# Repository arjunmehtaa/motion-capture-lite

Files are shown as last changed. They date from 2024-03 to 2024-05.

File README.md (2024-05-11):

# Motion Capture Lite
Project created as part of the FYDP Capstone (ECE 2024).

Created by: Arjun Mehta, Aryaman Singh, Kevin Kalathil, Nicolas Bao

## Project Abstract
The objective of this project is to build a “lite” motion-capture device that can accurately track small objects that are normally too difficult to track using just a camera. The device uses semi-passive imperceptible markers, which refer to projectors that illuminate small LED marker tags placed on objects. The marker tags are equipped with photosensors to detect light from a projector, and a microcontroller. The markers will process and communicate the results back to a computer where a software tool, through signal processing, converts recorded motion data from the device into 3D motion vectors and allows for real-time tracking.

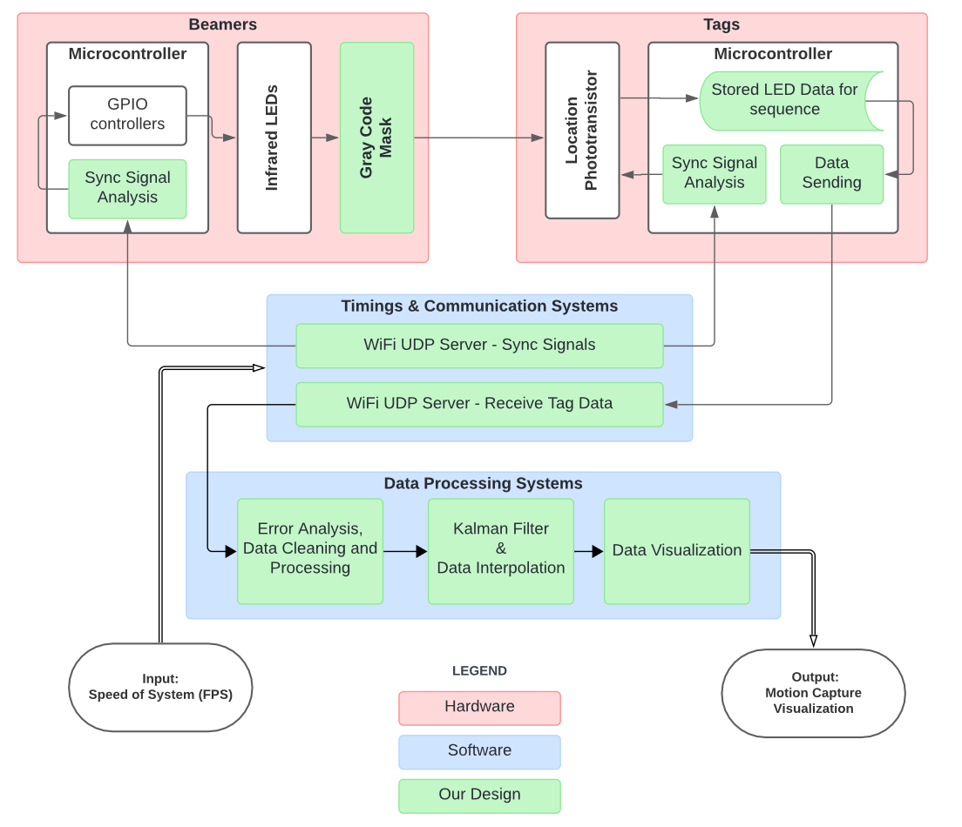
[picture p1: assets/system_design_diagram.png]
System Design


## Files
- `README.md`: This file.
- `report.pdf`: The final report for the project.
- `poster.pdf`: Poster for Capstone Presentation.

- `beamer_wifi.ino`: Arduino code for the beamers
- `tag_wifi.ino`: Arduino code for the tags
  
- `udp_server.py`: Python code for the server (receives data from the tags)
- `udp_server_calibrate.py`: Optional tool to help calibrate the system
- `visualizer.py`: 3D Visualization tool for tag motion (requires `matplotlib`)

- `rust_sender/*`: Rust code for the sender (sends data to the tags)

- `schematics/*`: Schematics for the project (tag and beamer)
- `old/*`: Old code and files - please ignore!

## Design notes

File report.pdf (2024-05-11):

University of Waterloo
Faculty of Engineering
Department of Electrical and Computer Engineering

# Motion Capture Lite

# Final Report

Group Number 14
Prepared by:
Name | Student Number | Email
Aryaman Singh | 20815224 | a55sing@uwaterloo.ca
Arjun Mehta | 20839709 | a47mehta@uwaterloo.ca
Kevin Kalathil | 20846153 | kkalathi@uwaterloo.ca
Nicolas Bao | 20828231 | n3bao@uwaterloo.ca

Consultant Name: Murray Dunne

Date: February 25, 2024

# Abstract

Motion Capture is a common technique used to track the movement of objects digitally. Used extensively by the entertainment, sports, and robotics industries, existing solutions are generally expensive and complex. They typically involve elaborate suits, large camera setups, and human-centered tracking. The objective of this project is to build a “lite” motion-capture device that can accurately track small objects that are normally too difficult to track using just a camera. The device uses semi-passive imperceptible markers, which refer to projectors that illuminate small LED marker tags placed on objects. The marker tags are equipped with photosensors to detect light from a projector, and a microcontroller. The markers will process and communicate the results back to a computer where a software tool, through signal processing, converts recorded motion data from the device into 3D motion vectors and allows for real-time tracking. This method allows the device to capture the motion of objects at high speed, using relatively simple and cheap electronics (photosensors and LEDs).

# Acknowledgments

We want to, first and foremost, express our gratitude to Professor Murray Dunne for his invaluable assistance over the past year. His guidance has played a crucial role in shaping the direction of this project since its inception, and we deeply appreciate his encouraging words and unwavering support throughout the entire process.

We are also extremely thankful to the original authors of Prakash: Lighting Aware Motion Capture using Photosensing Markers and Multiplexed Illuminators [1], which was published by the Mitsubishi Electric Research Laboratories (MERL) in Cambridge, MA - this paper was the original inspiration for our work, and though our project differs in implementation, it has been essential in our work.

Finally, we are thankful to the entire ECE department, professors, and TAs for their continued support through the FYDP process.

### University of Waterloo Territorial Acknowledgment

The University of Waterloo acknowledges that much of our work takes place on the traditional territory of the Neutral, Anishinaabeg, and Haudenosaunee peoples. Our main campus is situated on the Haldimand Tract, the land granted to the Six Nations that includes six miles on each side of the Grand River. Our active work toward reconciliation takes place across our campuses through research, learning, teaching, and community building, and is co-ordinated within the Office of Indigenous Relations.

# Table of Contents

Abstract | 1
Acknowledgments | 3
University of Waterloo Territorial Acknowledgment | 3
Table of Contents | 4
List of Figures | 5
List of Tables | 6
1. High-Level Description of Project | 7
1.1 Motivation | 7
1.2 Project Objective | 7
1.3 Block Diagram | 8
2. Project Specifications | 10
2.1 Functional Specifications | 10
2.2. Non-functional Specifications | 11
Table 2. Non-functional specifications | 11
3. Detailed Design | 12
3.1 Tags | 12
3.1.1. Physical Design | 12
3.1.2 Software Design | 14
3.2 Beamers | 16
3.2.1 Physical Design | 16
3.2.2 Software Design | 18
3.3. Timings and Communication | 20
3.3.1 Time Modulation Decision | 20
3.3.2 Beamer Timing Design | 20
3.3.3 Communication Protocol - WiFi | 21
3.4 Data Processing Software | 24
3.4.1 Software Architecture | 24
3.4.2 Data Visualization | 25
5. Discussion & Conclusions | 28
5.1 Evaluation of Final Design | 28
5.2 Use of Advanced Knowledge | 28
5.3 Creativity, Novelty, Elegance | 29
5.4 Quality of Risk Assessment | 30
5.5 Student Workload | 31
References | 32

# List of Figures

Figure Name | Page
Figure 1. Block Diagram of Motion Capture Lite | 8
Figure 2. Diagrams showing connections on the tag microcontroller | 13
Figure 3. Diagrams showing connections on the phototransistor circuit | 13
Figure 4. Image displaying PCB for tag and microcontroller | 14

Figure 5. Arduino (.ino) code snippet for tag microcontroller, showing the four steps

for reading, storing, and sending the values. | 15
Figure 6. Circuit diagram for the buck converter on the beamer PCB | 16
Figure 7. LED and Mosfet diagrams for beamer PCB | 17
Figure 8. Circuity diagram showing MC terminal connections and GPIO connections | 17
Figure 9. 3D models of the beamer casing | 18

Figure 10. Sample 3D-printed casing with microcontroller and PCB - important

components are labeled in the diagram for convenience. | 18
Figure 11. Timing diagram for beamer | 20
Figure 12. Block diagram of a 6 LED beamer | 21

Figure 13: Block diagram depicting wireless communication between server-beamer

and server-tag | 22
Figure 14. Flow Architecture of the Location Processing Algorithm. | 24
Figure 15. Demo of Data Visualization using Python’s Matplotlib. | 26
Figure 16. Showing how the trail animations were created in Python Matplotlib | 27

# List of Tables

Table Name | Page
Table 1. Functional Specifications | 10
Table 2. Non-functional specifications | 11
Table 3. Requirements for phototransistor on tag | 12

Table 4. Variation of ADC Values from the microcontroller depending on the distance

between the tag and beamer | 13
Table 5. Requirements of Location LED on Beamer | 16
Table 6. Performance of LED detection depending on reading window | 19

Table 7. Variation of dropped packets with respect to the interval between sync

signals | 23
Table 8. Decision Matrix for visualization tool | 25
Table 9. Evaluation of functional requirement analysis | 28
Table 10. Quality of Risk Assessment table | 30
Table 11. Student Workload Table | 31

# 1. High-Level Description of Project

## 1.1 Motivation

Motion Capture is a common technique used to track the movement of objects digitally. The global market for motion capture is valued at around US$180M as of 2022 and is expected to reach US$600M by 2030. [2] Used extensively by the entertainment, sports, and robotics industries, existing solutions are generally expensive and complex, with most options costing thousands of dollars. [3] They typically involve elaborate suits, large camera setups, and human-centered tracking. The objective of this project is to build a “lite” motion-capture device that can accurately track small objects such as in-game props that are normally too difficult and too costly to track using a camera.

The device uses semi-passive imperceptible markers [1], which refer to projectors that illuminate small LED marker tags placed on objects. The marker tags are equipped with photosensors to detect light from a projector, and a microcontroller. The markers process and communicate the results back to a computer where a software tool, through signal processing, converts recorded motion data from the device into 3D motion vectors and allows for real-time tracking. This method allows the device to capture the motion of objects at high speed, using relatively simple and cheap electronics (photosensors and LEDs).

## 1.2 Project Objective

The objective of this project is to design a relatively low-cost motion capture system to track objects and props using semi-passive imperceptible markers and photosensors. The sensors process and send results to a computer, where the captured data can be used to visualize objects in motion.

## 1.3 Block Diagram

The block diagram for our project is as follows:

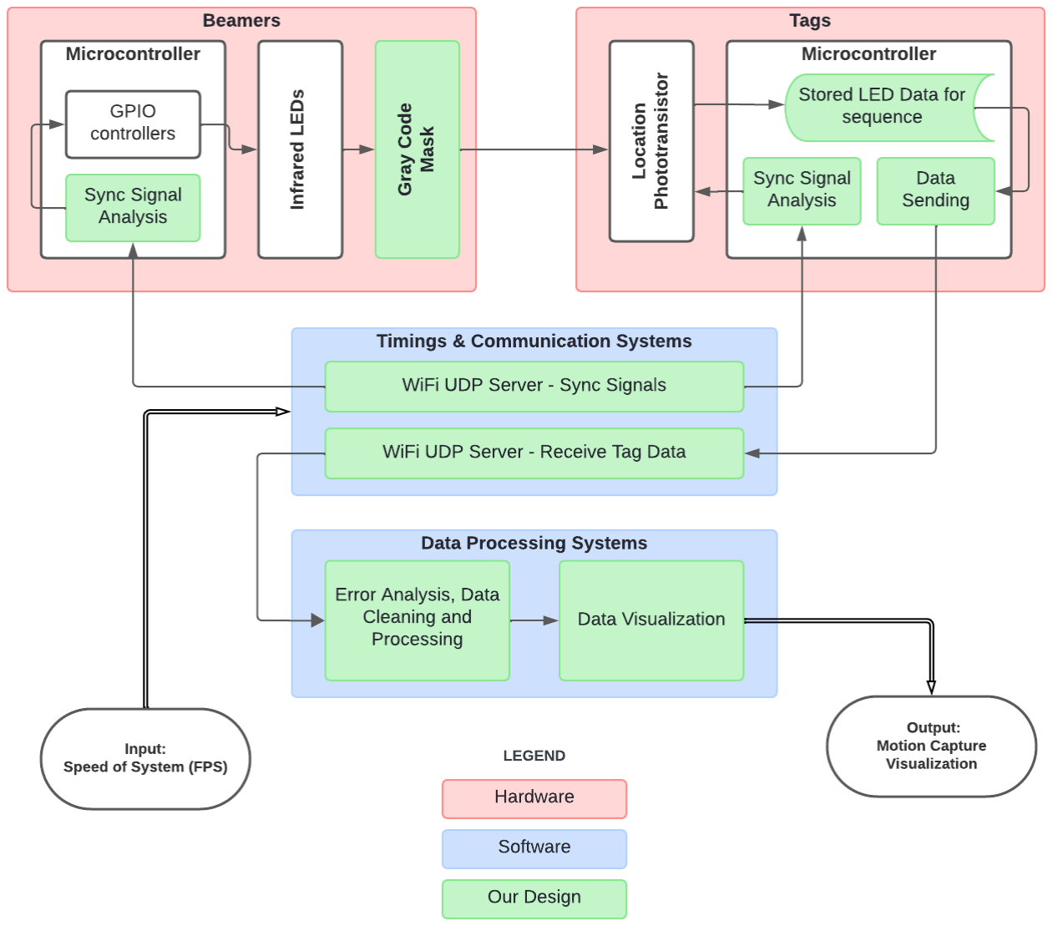
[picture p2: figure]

Figure 1. Block Diagram of Motion Capture Lite

We have 4 subsystems as part of our project:

### 1. Beamers (Transmitters): The beamer components consist of a microcontroller, which

receives a SYNC signal to begin transmitting. The transmission happens using the GPIO pins of the microcontroller, which turn on each of the 6 LEDs sequentially, at speeds up to 10ms per LED. A gray code mask is placed in front of the LEDs to uniquely identify each beamer. A single beamer is used to identify a tag’s location within a specific axis.

2. Tags (Receiver): The tags are to be attached to the object of interest and each tag will be used as a reference to describe the object’s movement. The tag begins observing the LEDs using its phototransistor when it receives a SYNC signal, stores the sequential data for all 6 LEDs, and sends the data to the server when it has received all the required data.

### 3. Timings & Communication Systems: This subsystem consists of a server that sends a

SYNC signal to all the beamers and tags at the same time, ensuring that the beamers and tags are coordinated correctly. This subsystem also receives the data from the tag microcontroller and sends it to the data processing systems.

### 4. Data Processing System: This subsystem takes in the voltage values communicated by

the tag to the server, performs error correction and data analysis on it, and then parses the data to determine the position of the tag in 2D/3D space. Data visualization software is used to display the position.

# 2. Project Specifications

## 2.1 Functional Specifications

Specification | Subsystem | Description | Necessity
Sensor integration | Tags (Receiver) | Each tag contains a phototransistor which is used for location tracking. | Essential
Data Processing | Data Processing Software, Tags/Receiver | Take a bitstream from each tag and use Location Vector algorithms such as triangulation to convert raw data from the photosensors into 3D motion data | Essential
Communication | Beamer (Transmitter), Tags (Receiver)

A tag’s microcontroller communicates results from phototransistors to the server. The computer sends a sync signal to all tags and beamers.

Essential

Data Storage | Tags (Receiver) | Tags should maintain a bit stream that will be used to resolve its position. This data is to be stored on the microcontroller’s on-device Flash memory.

Essential

Real-time
streaming

Data Processing
Software, Tags
(Receiver)

The data recorded by the microcontroller should be relayed to software that converts and processes the raw data stream. Real-time streaming enables a better user experience and decreased memory usage on the device.

Non-Essential

Table 1. Functional Specifications

## 2.2. Non-functional Specifications

Specification | Subsystem | Description | Necessity
Lightweight | Tags | As these tags are going to be placed on moving objects, they need to be light. | Essential
Cheap | Tags | Since we may need numerous tags on a single object or we want to track multiple objects simultaneously. We would like the tags to be cheap to produce. | Non-Essential
Portable | Tags | One of the main benefits of this type of motion capture is the simplicity of the system components. This simplicity can also allow for more portable devices

Non-Essential

Scalable | Software, Tags | The system should scale with any number of sensors that are added to the system.

Non-Essential

Table 2. Non-functional specifications

# 3. Detailed Design

## 3.1 Tags

### 3.1.1. Physical Design

The design of the tag is relatively simple - it consists of a phototransistor that is designed to be able to detect when the infrared LED is turned on. The requirements of the phototransistor are as follows:

Angle of Detection | Intensity falloff vs distance | Intensity falloff vs angle | Light spectrum
Narrow | Minimum | Sharp | Infrared
Table 3. Requirements for phototransistor on tag

The phototransistor that we selected is the Würth Elecktronik 1541201NEA400 [4], which fulfills all of these requirements. It is important to note that in the context of our circuit, the phototransistor acts as a current source, and the ADC of the microcontroller reads the voltage across the resistor. This can be seen in the figure below:

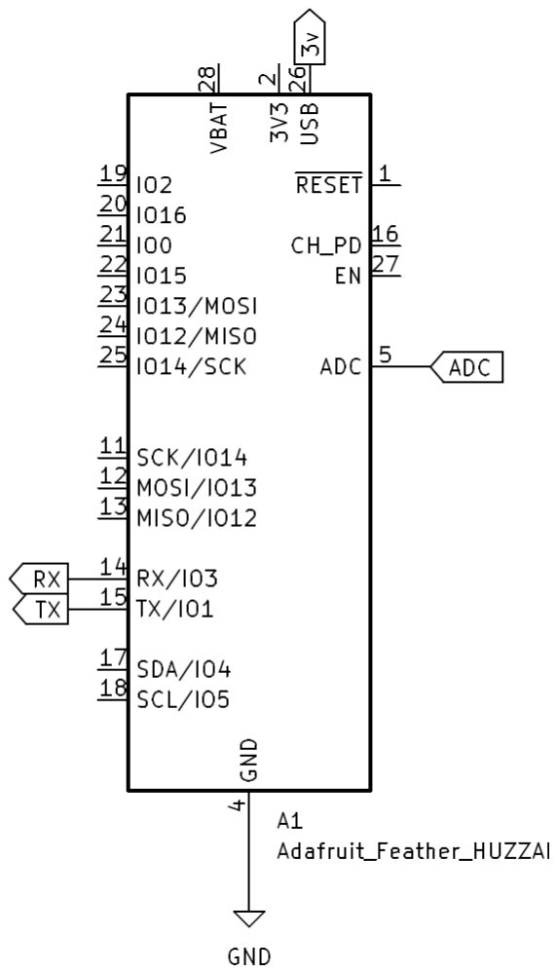
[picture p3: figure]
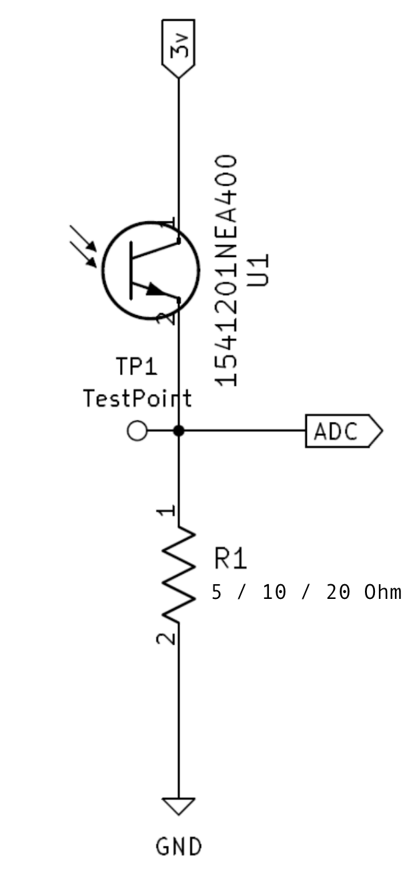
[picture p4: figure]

Figure 2/3. Diagrams showing connections on the tag microcontroller (left) and the phototransistor circuit (right). Note the R1 resistance on the phototransistor circuit.

Thus, our phototransistor can have different sensitivities depending on the value of the resistance. Different sensitivities have different relationships with the voltage values being read by the ADC (Analog to Digital Converter) in the tag. To quantify this relationship, we placed an infrared LED a certain distance away from the phototransistor and observed how the ADC values changed depending on the sensitivity of the photosensor:

Sensitivity of Photosensor Resistor (R1) | Distance between phototransistor (tag) and LED (beamer)
1- 2 inches 1 (High Value) | 2 feet | 4 feet | LED Off (Base Value)
Low - 5 Ohm | 27 | 14 | 7 | 4
Medium - 10 Ohm | 120 | 64 | 12 | 7
High - 20 Ohm | 673 | 104 | 31 | 8
Table 4. Variation of ADC Values from the microcontroller depending on the distance between the tag and beamer (i.e. phototransistor and IR LED)

1 This distance is impractical for the final product due to the 3D printed casing around the tags/beamers, but gives us an idea of the highest possible value the phototransistor can output.

As anticipated, the highest sensitivity resistor yielded the widest range of ADC values. Despite being conducted in ideal conditions, this extended range suggests reliable LED differentiation even in unfavorable lighting. While a higher sensitivity may result in a slightly elevated base value (only 1-4 units more than lower/medium sensitivity resistors in our tests), the benefits outweigh this minor drawback.

Below, we can see our final tag PCB along with the microcontroller:

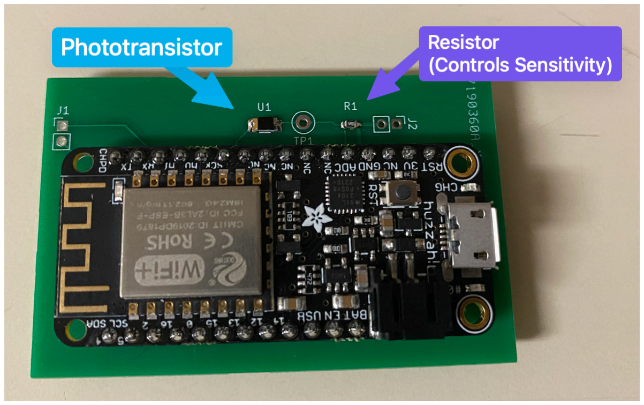
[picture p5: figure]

Figure 4. Image displaying PCB for tag and microcontroller

### 3.1.2 Software Design

The tags are required to meet certain timing deadlines which makes them real-time systems. The software for the tag is responsible for detecting the gray-coded LED signals from the beamers that are being polled by a controller. The tag begins detecting light from the LEDs when the synchronization signal is received from the WiFi server. It periodically checks if it detects an LED, and each time period corresponds to a different LED. At any given point, only one LED would be on. Originally, we had designed our tags to decode the gray-coded signals themselves, by setting a minimum and maximum voltage reading which would count as an LED being on. However, we now send the raw ADC values for each sequence directly to the WiFi server, thus reducing the processing on the tag end.

The overall algorithm can be simplified to these 4 steps:

### 1. Receive a SYNC signal from the server: Note that since reading the contents of a UDP

packet takes time, we simply use the presence of a UDP packet to indicate synchronization.
2. Set inputVoltage for LED: During the reading window for any given LED, set inputVoltage to be the maximum voltage read in that window
- Note that voltage here does not refer to V, but rather the unitless value generated by the ADC.
3. Add current value to packet: When the reading window for any given LED is over, add the inputVoltage to the packet.
4. Send packet to server: When all 6 LEDs have been read, send the packet to the server.

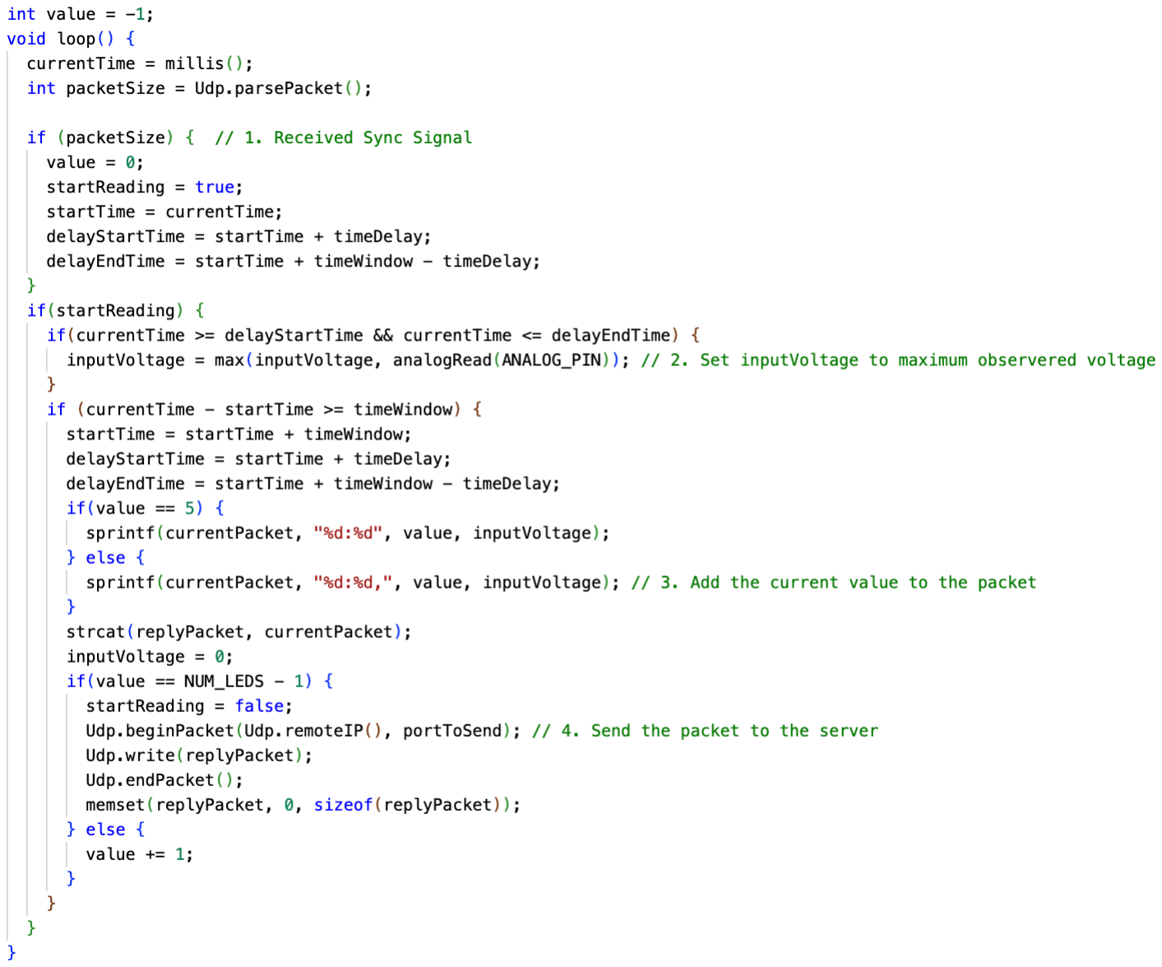
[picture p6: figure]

Figure 5. Arduino (.ino) code snippet for tag microcontroller, showing the four steps for reading, storing, and sending the values.

## 3.2 Beamers

### 3.2.1 Physical Design

The beamer's core function is to control the on/off states of 6 location LEDs. These LEDs, along with the gray code mask, enable the tag's positional detection of the beamers. The pivotal element in the beamer design is the LED, which must meet the following requirements:

Brightness | Cost | Angle | Wavelength
High | Low | Narrow (can be done with physical design) | Infrared
Table 5. Requirements of Location LED on Beamer

The LED we chose is the VSMA 1094250 [5], which fulfilled all of these requirements. Only 1 LED would be turned on at a time, which meant that we did not have to account for the power requirements of all LEDs being on at the same time.

However, since these LEDs require 3V at 1A (which is more than the board power supply of 3.3V at 250 mA), an external power source is needed. A 9V battery is chosen as our power source due to its simplicity and high availability, and a fuse is attached to the battery for safety. A buck converter is added to step down the voltage to 3.3V, which can be seen in the diagram below:

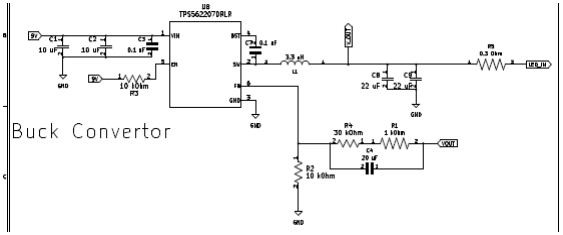
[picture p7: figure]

Figure 6. Circuit diagram for the buck converter on the beamer PCB

Mosfets in series with the LEDs allow us to control which LEDs are on via the GPIO pins of the microcontroller. Figures showing the configuration of the LEDs and Mosfets, as well as how the

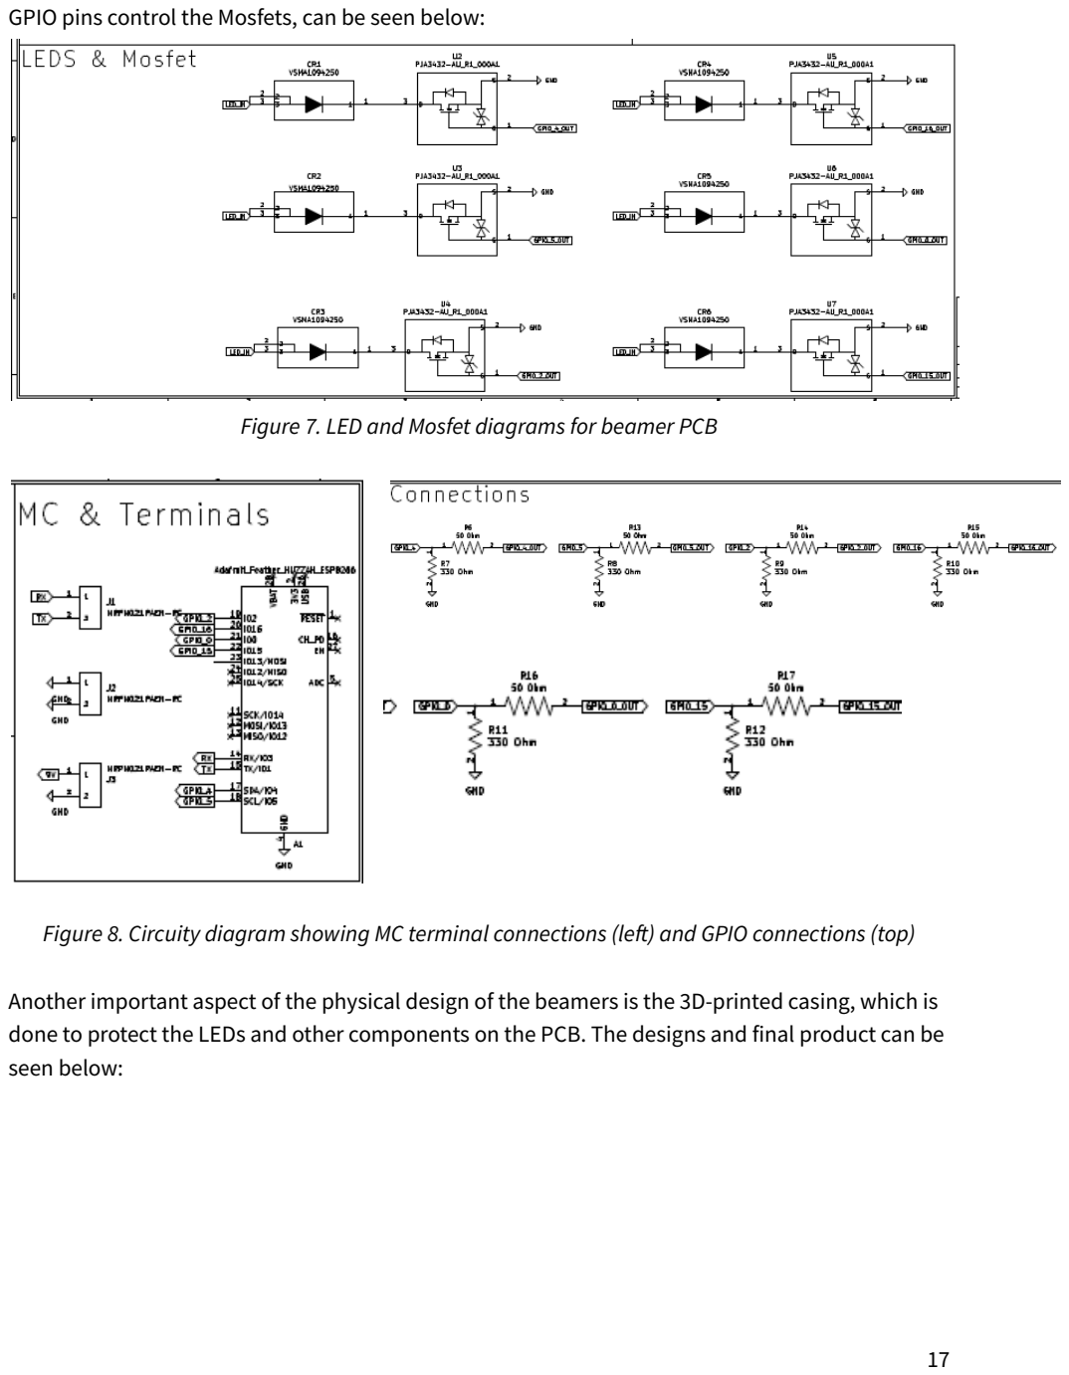
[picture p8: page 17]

GPIO pins control the Mosfets, can be seen below:

Figure 7. LED and Mosfet diagrams for beamer PCB

Figure 8. Circuity diagram showing MC terminal connections (left) and GPIO connections (top)

Another important aspect of the physical design of the beamers is the 3D-printed casing, which is done to protect the LEDs and other components on the PCB. The designs and final product can be seen below:

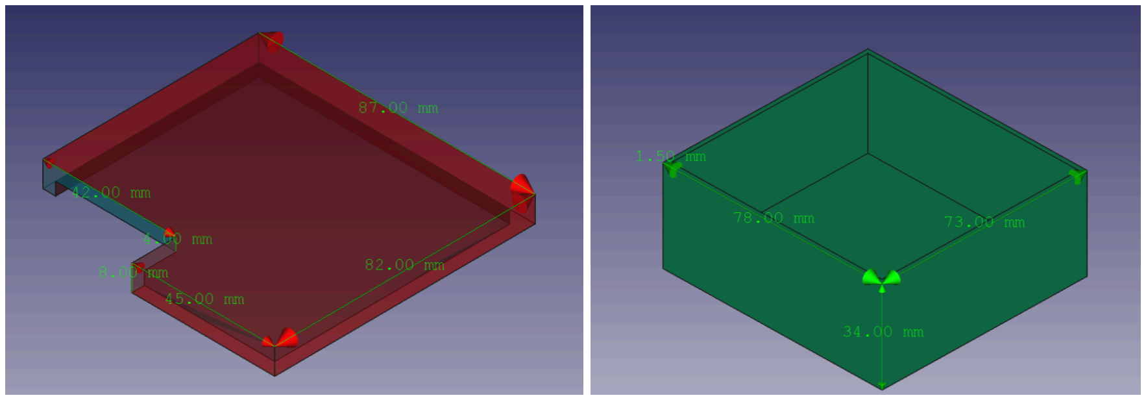
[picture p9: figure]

Figure 9. 3D models of the beamer casing

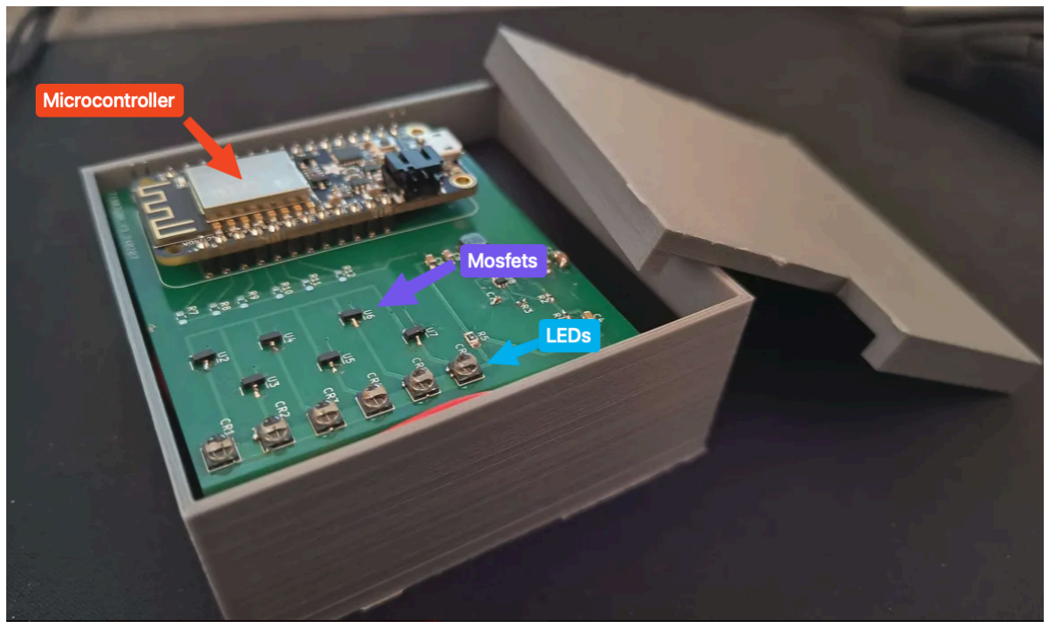
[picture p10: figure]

Figure 10. Sample 3D-printed casing with microcontroller and PCB - important components are labeled in the diagram for convenience.

### 3.2.2 Software Design

The beamers play a crucial role in the timing and speed of our entire system. The rate at which we can cycle between LEDs directly affects the overall speed (i.e. frames per second) we can get in our motion capture system. This requires us to determine the fastest rate at which the LEDs can be cycled through

2 while ensuring that the phototransistor accurately captures each LED without any miscount or mapping errors.

2 For more information about the timing system, see Section 3.3 below.

To test this, we turn on only one LED out of the 6 (LED #3 in this case), and observe how fast we can go without the phototransistor missing the LED or thinking it came from another LED. In other words, the 6 LEDs output 0 0 1 0 0 0, and we expect the phototransistor to return this value. For each time window, we ran this experiment for 100 cycles.

Time Window LED stays on | Number of cycles with missed LEDs | Number of cycles with leaks into previous/next LED reading (i.e LED 2 or LED 4 ) | Comments
100ms | 0 | 1 | The phototransistor can sense the LEDs correctly most of the time for the given time window
50ms | 0 | 2 | The phototransistor can sense the LEDs correctly most of the time for the given time window
10ms | 5 | 8 | The phototransistor can sense the LEDs correctly with a few misses.
6ms | 30 | 50 | The tag is unable to sense the LED within the given time window for a large number of cycles

Table 6. Performance of LED detection depending on reading window

For the 6ms time window, we observe a large number of leaks where the tag believes the phototransistor reading corresponds to the previous/next LED, which could be a result of a slight delay between the tag and beamer receiving the SYNC signal. This indicates that this time window is too small for the phototransistor to sense the LED reliably.

Thus, we concluded that we could go as fast as 10ms per LED without compromising the accuracy of the phototransistor readings (and hence the location calculation) for the tag. A smoothing algorithm and results from previous cycles can be used to make up for any missed readings.

## 3.3. Timings and Communication

### 3.3.1 Time Modulation Decision

One of the downsides of using a phototransistor is its limited resolution as they can not differentiate between light sources. The big question, then, is - how do we avoid detecting light from the wrong LED?

One solution would be to use LEDs that emit light at a specific wavelength and have only one type of phototransistor that can detect that wavelength. There are many issues with this approach, mainly that getting LEDS and phototransistors that can emit and detect in a narrow band of the spectrum is expensive and not aligned with our goal of making the final model product affordable.

We are limited by the cost of LEDs and transistors, so our other option is time modulation. By only reading the values from our sensors during specific time intervals we can “allocate” a time for our beamers to communicate with our sensors.

### 3.3.2 Beamer Timing Design

The beamer’s sole function is to display a gray code light pattern for tags to observe.

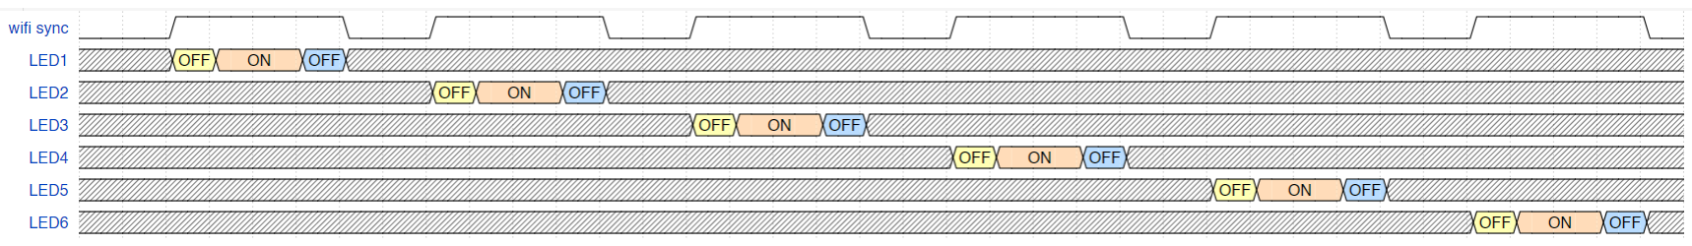
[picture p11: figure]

Figure 11: Timing diagram for one cycle of the beamer’s six LEDs

To further elaborate on how the gray code is sent, the LEDs are lined up and turned on and off in a sequence. Each LED is covered by a 3D-printed gray code mask which blocks light within certain regions only allowing tags within certain regions along the beamer’s plane to observe the emitted light. Since they are enabled sequentially, with each result (observed or not observed), we can halve the possible region where the tag may be located. Refer to Figure 4 for the general layout and timing of a 6 LED tag and gray coding.

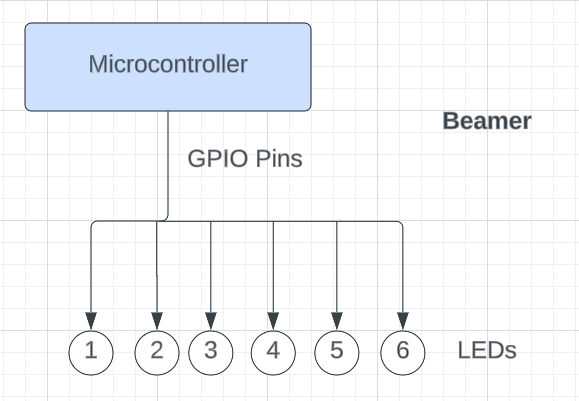
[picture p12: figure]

Figure 12: Block diagram of a 6 LED beamer

### 3.3.3 Communication Protocol - WiFi

Since the system requires high-speed transmission and low-latency data streaming, communication between server-tag and server-beamer is done wirelessly using the UDP protocol, and we use our own router to establish a stable wireless connection between the devices. The UDP socket is set to non-blocking mode, allowing continuity in the case of lost packets. We can handle the lost data by using data from the previous cycle and integrating smoothing algorithms.

The server sends a SYNC signal to a single beamer as well as all the tags at the same time, each listening on their own IP address respectively. Upon receiving the SYNC signal, the beamer turns on its LEDs one-by-one in sequence. The tags return a sequence containing the maximum photo sensor reading they observed for each LED to the server (which is always listening on its IP address on a separate thread). The server then repeats the cycle for the next beamer.

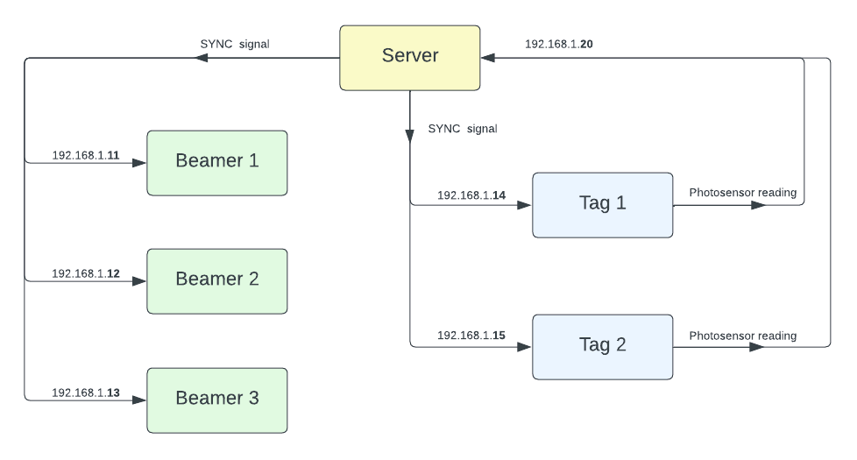
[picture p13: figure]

Figure 13: Block diagram depicting wireless communication between server-beamer and server-tag

Note that the IP addresses used in Figure 6 are placeholders, and they can be configured as required.

So far we have looked at timings for one tag and one beamer, but for our motion capture system to work in 3 dimensions, we need at least three beamers. If the beamers are independent of each other and fire off their LEDs at random, we encounter the same issue of not being able to identify the origins of the LEDs. To resolve this problem, we have decided to synchronize the beamers and have them fire in sequence after one another. To do this, we have to establish a way to coordinate communication across separate beamers.

To manage this task of coordinating separate beamers and tags, we synchronize the entire system using a centralized server stub that handles wireless data transmission, receiving, and processing.

The server, which is a program running on a separate computer, sends out periodic sync signals to all devices (beamers and tags) such that they all know when to emit or observe light, depending on whether the device is a tag or beamer. With the target of 5 frames per second (FPS), we would need to hit an effective clock speed of approximately 11ms per beamer.

We originally intended to send a separate sync signal for each packet but quickly realized that the low latency and high number of packets being transmitted was not feasible.

The following are the results of a test we performed to determine how quickly we could transmit data from the server to a single microcontroller. On the server code, we transmitted a counter value and on the receiver end, we logged the received counter value. If a counter value is missed, that is considered a drop. We tested by sending counter values from 1-200 and analyzing the output on the microcontroller logs.

Time Interval between
synchronization signals

Number of
dropped packets

Comments

50ms | 0 | The target device receives each packet in order and on time
10ms | <=2 | Based on our trials, we never drop more than 5 packets at 10 ms which is recoverable with smoothing, but still not ideal
5ms | <=20 | 20 missed packets in 200 transmissions is not ideal/recoverable.

Table 7. Variation of dropped packets with respect to interval between sync signals

Based on these test results, we then opted for a batching/sequencing approach where the sync signal received represents six cycles. In the case of the beamer, it executes its complete six LED sequence after receiving a sync signal, and the timing delays are handled within the microcontroller code that is flashed on the board. This increases the time between sync signals and decreases the number of packets transmitted by a factor of six. Hence, to achieve an effective clock cycle of 10ms for each LED being toggled, we only need to send packets every 60 ms which is achievable given the current system and its limits (as discussed in Section 3.2.2).

## 3.4 Data Processing Software

### 3.4.1 Software Architecture

Before beginning programming the data processing software, we first conceived what the design architecture should look like. As per our ECE 452 knowledge, we decided that a Pipe & Filter architecture would fit our project the best. Pipe & Filter architecture specializes in software that is heavy in processing, and where the flow of data is fairly linear. See Figure 7 to see an example of Pipe & Filter architecture used to determine the location of the tags using sensor data:

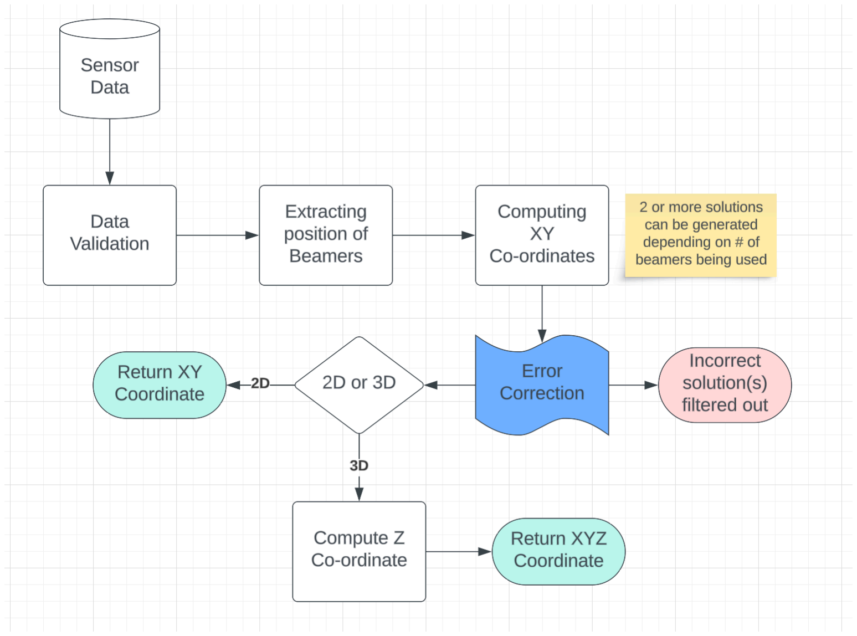
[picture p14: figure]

Figure 14. Flow Architecture of the Location Processing Algorithm. Pipe & Filter architecture can be clearly seen by the each architectural component is a process, and the flow of the data is linear. Error Connection symbolizes one of the filter components.

Data validation is done by simply ensuring that the values received from the tag match the range of the ADC values of the phototransistor, which is determined during our testing of the tag (as explained in Section 3.1.1).

### 3.4.2 Data Visualization

Once we have the coordinates of the tags, our next goal is to visualize the data. Our primary emphasis in developing the motion data visualization is to ensure that we design a system that is fast, easy to run on low-scale hardware, and easy to implement. Given the importance placed on our hardware within our project scope, our objective is to design a system that seamlessly integrates with our hardware, minimizing potential complications.

During the consideration of data visualization software, we explored various options, such as Python's Matplotlib, and Rust's egui, among others. We decided to use a decision matrix to come to the final conclusion on which visualization software to use, with a scoring range from 1 (Low) to 3 (High):

Criteria | Matplotlib (Python) | EGUI (Rust) | Qt (C++) | Tkinter (Python) | Electron (JS/TS)
Ease of Integration 3 | High (3) | High (3) | Low (1) | High (3) | Low (1)
Performance (higher FPS, animation smoothing) | Moderate (2) | High (3) | High (3) | Low (1) | Low (1)
Cross-Platform Support | High (3) | Moderate (2) | Moderate (2) | Medium (3) | High (3)
Flexibility (ability to create custom GUI components) | Moderate (2) | Low (1) | Moderate (2) | Moderate (2) | High (3)
Prior Team Experience | High (3) | Moderate (2) | Low (1) | Medium (2) | High (3)
Visual Appeal | Moderate (2) | Low (1) | Low (1) | Moderate (2) | High (3)
Total | 15 | 12 | 10 | 13 | 14

Table 8. Decision Matrix for visualization tool

3 During the discussion on which visualization software to use, we were already using Rust and Python for parts of our server and networking code, which is why tools that used these languages were given a High rating.

In the end, we ended up using Python’s Matplotlib, primarily due to its ease of use and easy integration with our existing codebase. Another advantage of Matplotlib is its easy implementation of 3D visualization [6], which some other visualization tools did not support.

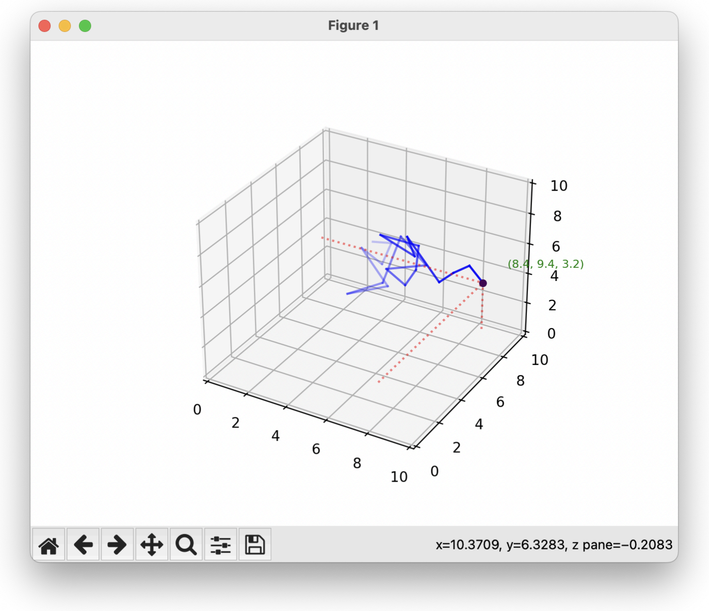
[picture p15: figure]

Figure 15. Demo of Data Visualization using Python’s Matplotlib. The point is labeled and has red lines indicating shadow on the axes.

A very simple animation algorithm is applied to ensure a “smooth” path of the motion capture data can be shown. The previous 20 (or so) points were stored and graphed, and lines connecting these points with decreasing transparency were added to visualize a “trail” behind the point:

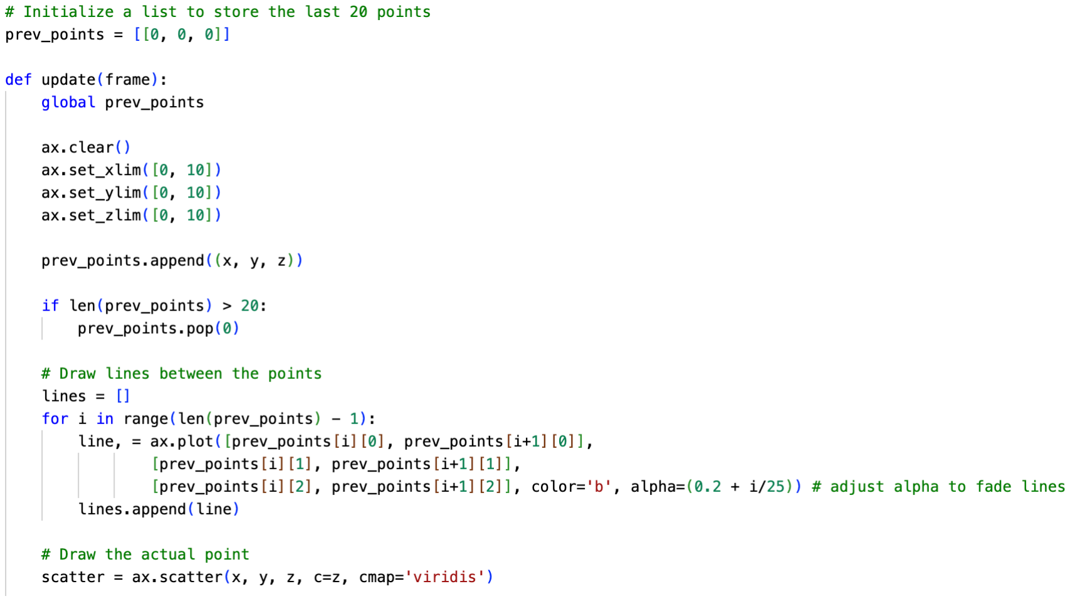
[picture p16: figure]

Figure 16. Showing how the trail animations were created in Python Matplotlib

Through this system, it is evident that we were able to achieve our requirements of real-time streaming of data from the tags to a visualization that can be seen, understood, and recorded with ease.

# 5. Discussion & Conclusions

## 5.1 Evaluation of Final Design

The objective of this project is to design a relatively low-cost motion capture system. The design proposed in the report meets the essential functional and non-functional specifications listed in Section 2.1 and Section 2.2 respectively. The design covers how the hardware and software of the tag (receiver) and beamer (transmitter) would be set up, as well as how they would communicate with the main software. The final design, integrated with 3D visualization, meets non-essential functional requirements such as real-time streaming, allowing users to track objects being moved in real-time.

Functional
Requirement
| Status | Description
Sensor integration | Done (tag) | Integration of phototransistor on tag is done successfully, as shown in section 3.1
Data Processing | Done | Data visualization is done successfully, as shown in section 3.4
Communication | Done (between tag, beamer and server) | Communication is achieved through WiFi and UDP, as shown in Section 3.3
Data Storage | Done (on tag itself) | Tags are successfully able to store the data for each LED locally, before sending it to the server.
Real-time streaming | Done (demo of visualization) | Data visualization can be done in real-time, as shown in Section 3.4

Table 9. Evaluation of functional requirement analysis

As for non-functional requirements, the hardware components comprising the tag were carefully picked to ensure that the tags were compact and lightweight. A 3D-printed container is also created for the devices to ensure safe, portable, and easy usage of the motion capture system.

## 5.2 Use of Advanced Knowledge

During the research, analysis, and design phases of the project, knowledge from upper-year ECE courses including ECE 455, 452, 458, and 327 were required.

Due to the need for controlling electronics on our projectors and tags, we needed to use our understanding of Embedded Software programming (ECE 455 & ECE 327) to identify microcontrollers that would most appropriately satisfy the timing requirements of the projector along with the form factor requirements for the tags. In order to meet the timing requirements of the projector, which iterates through the different gray codes through time modulation. When selecting the Huzzah ESP 8266 microcontroller, we factored in the clock speed which impacts the WCET of the system which was one of the major topics covered in ECE 455: Embedded Software.

In order to analyze the synchronization, timing, and communication of the various subsystems, knowledge of timing diagrams was required in order to outline expected workloads, which we had learned in ECE 327: Digital Hardware Systems. Additionally, we made sure to consider various timing delays including setup/hold times, and clock jitter which we accounted for in timing diagrams by including delays between state changes.

For the software sub-systems in our projects, we made heavy use of the software architecture skills we were taught in ECE 452: Software Design & Architecture, such as the pipe and filter system described earlier. We also used Rust and its many performance paradigms (such as Tokio and multithreading) while designing our server and networking systems, which we learned about in ECE 459: Programming for Performance. We also made heavy use of the networking concepts taught to us in ECE 358: Computer Networks such as gateways, subnet masks, IP address configuration, UDP protocol, and routing.

## 5.3 Creativity, Novelty, Elegance

One novel aspect of our project is that in contrast to conventional camera-based motion capture systems, where cameras capture the light reflected by the markers, our system utilizes projectors as the "cameras" that transmit the light, and tags on the tracked object to receive the light. This is the reverse of how the vast majority of motion capture (and camera systems) work in general. As discussed, this allows us to creatively use low-cost sensors and LEDs for the tracking.

A creative aspect of our project is the implementation of gray coding to identify different tags. Gray coding is a binary encoding scheme that minimizes errors when transitioning between marker states. This is most commonly used for digital signal communication in electronics and is not usually used in typical camera or computer-vision-based motion capture systems. Our implementation of this idea in the motion capture space is required because of our “inverted” motion capture, which requires us to use something like gray coding to uniquely identify the position of each LED tag.

Another novel aspect of our motion capture is imperceptible markers and photosensors. Unlike traditional systems that rely on active markers or sensors, we have eliminated the need for bulky tags that can interfere with the natural movement of the object being tracked.

## 5.4 Quality of Risk Assessment

The following table shows the risks we assessed during the 4A terms and the steps we took to address them.
Risk | Description | Steps Taken
Time management | Balancing time between FYDP and other demanding courses taken by the team members during the 4A and 4B academic terms | We set up weekly meetings, met in-person as much as possible, and recorded the project progress in a project management software, which helped us stay on track with tasks
Shipping delays in hardware components | Since these components are usually shipped from other countries, they can take long to be delivered | Being aware of this risk allowed us to order components ahead of time from reputable websites. We ordered the components we needed in the 4B term months before the term started
Slow software processing | The server (especially if written in Python) could struggle with processing large volumes of real-time data at high speeds, which is a requirement for our project | We migrated our server code from Python to Rust and integrated multithreading for sending and receiving data over WiFi to ensure our code is optimized to process data in real-time
Electrical circuitry safety risk | As the tags are supposed to be placed on an object, there could be a safety risk due to the electrical circuitry | We developed a 3D-printed enclosure for the tag and made sure to test only with dry objects, away from the vicinity of conductive liquids. Additionally, we use fairly large objects for testing to ensure that two tags on the same object are not in close proximity to each other. We also recorded chip temperatures during our testing to check for any thermal/fire hazards.

Table 10. Quality of Risk Assessment table

## 5.5 Student Workload

We met with the consultant every week to share our progress in the preceding week and to set goals for the upcoming week. We also conducted a team meeting every 2 weeks to discuss broader goals and prepare for upcoming deadlines. Additionally, we divided the work among team members and kept members working on hardware and software in sync through a group chat. The workload and contribution of each student are presented in the table below, based on the number of hours each student contributed towards the project and course deadlines.

Group Member | Contribution/Workload (in %)
Aryaman Singh | 24
Arjun Mehta | 22
Kevin Kalathil | 24
Nicolas Bao | 30
Table 11. Student Workload Table

The observed contribution/workload is close to the expected average workload of 25% per student. The slightly uneven workload distribution is due to one of the members being on co-op term during the summer (4A) term, making them unable to work in person on hardware during that term.

# References

[1] R. Raskar et al., “Prakash: Lighting Aware Motion Capture using Photosensing Markers and Multiplexed Illuminators” [Online]. Available: https://web.media.mit.edu/~raskar/LumiNetra/Paper/CONFIDENTIALraskarSig07OpticalMocapPaper.p df. [Accessed: Jun. 29, 2023]
[2] Z. M. Research, “Global 3D Motion Capture System Market Size: Revenue Valued at USD 180 Million in 2022, Expected to Reach USD 600 Million by 2030 at a CAGR of 14.12%,” GlobeNewswire News Room, Apr. 04, 2023.
https://www.globenewswire.com/en/news-release/2023/04/04/2640330/0/en/Global-3D-Motion-Capt ure-System-Market-Size-Revenue-Valued-at-USD-180-Million-in-2022-Expected-to-Reach-USD-600-Milli on-by-2030-at-a-CAGR-of-14-12.html#:~:text=filingsmedia%20partners-.
[Accessed Jun. 29, 2023]
[3] “How much does a motion capture system cost? - Racket Source,” Racket Source, Apr. 06, 2022. [Online]. Available:
https://www.racketsource.com/articles/how-much-does-a-motion-capture-system-cost-cb40dc73. [Accessed: Jun. 29, 2023]
[4] “Dimensions: [mm].” [Online]. Available: https://www.we-online.com/components/products/datasheet/1541201NEA400.pdf [Accessed: Feb 5, 2024]
[5] “VSMA1094250.” [Online]. Available: https://www.vishay.com/docs/80299/vsma1094250.pdf [Accessed: Feb 5, 2024]
[6] “Three-Dimensional Plotting in Matplotlib | Python Data Science Handbook,” jakevdp.github.io.
https://jakevdp.github.io/PythonDataScienceHandbook/04.12-three-dimensional-plotting.html
[Accessed: Feb 21, 2024]

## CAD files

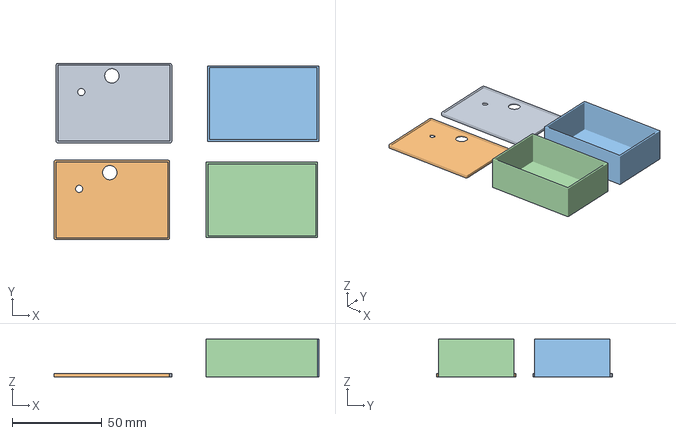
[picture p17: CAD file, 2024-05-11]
schematics/Lid_tag-tag_lid_complete.3mf
147.3 x 98.1 x 21.0 mm
Lid_tag-tag_lid_complete.stl x 2
Box_tag-Tag_box_empty.stl x 2

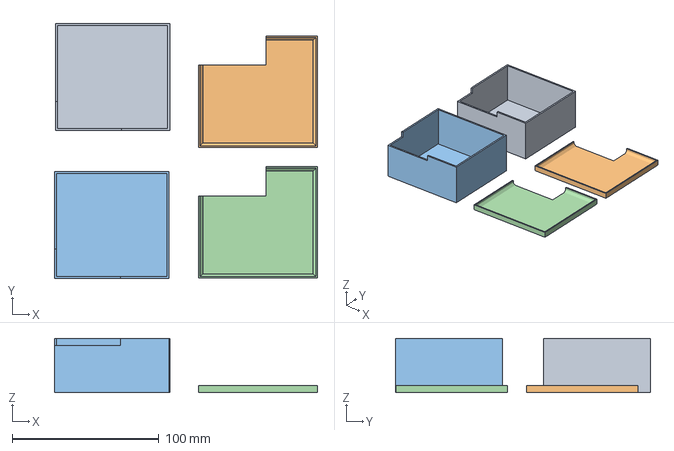
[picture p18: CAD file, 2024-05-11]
schematics/Beamer_Model.3mf
179.1 x 173.6 x 37.0 mm
Beamer_box_complete.stl x 2
Lid_beamer-Cut.stl x 2

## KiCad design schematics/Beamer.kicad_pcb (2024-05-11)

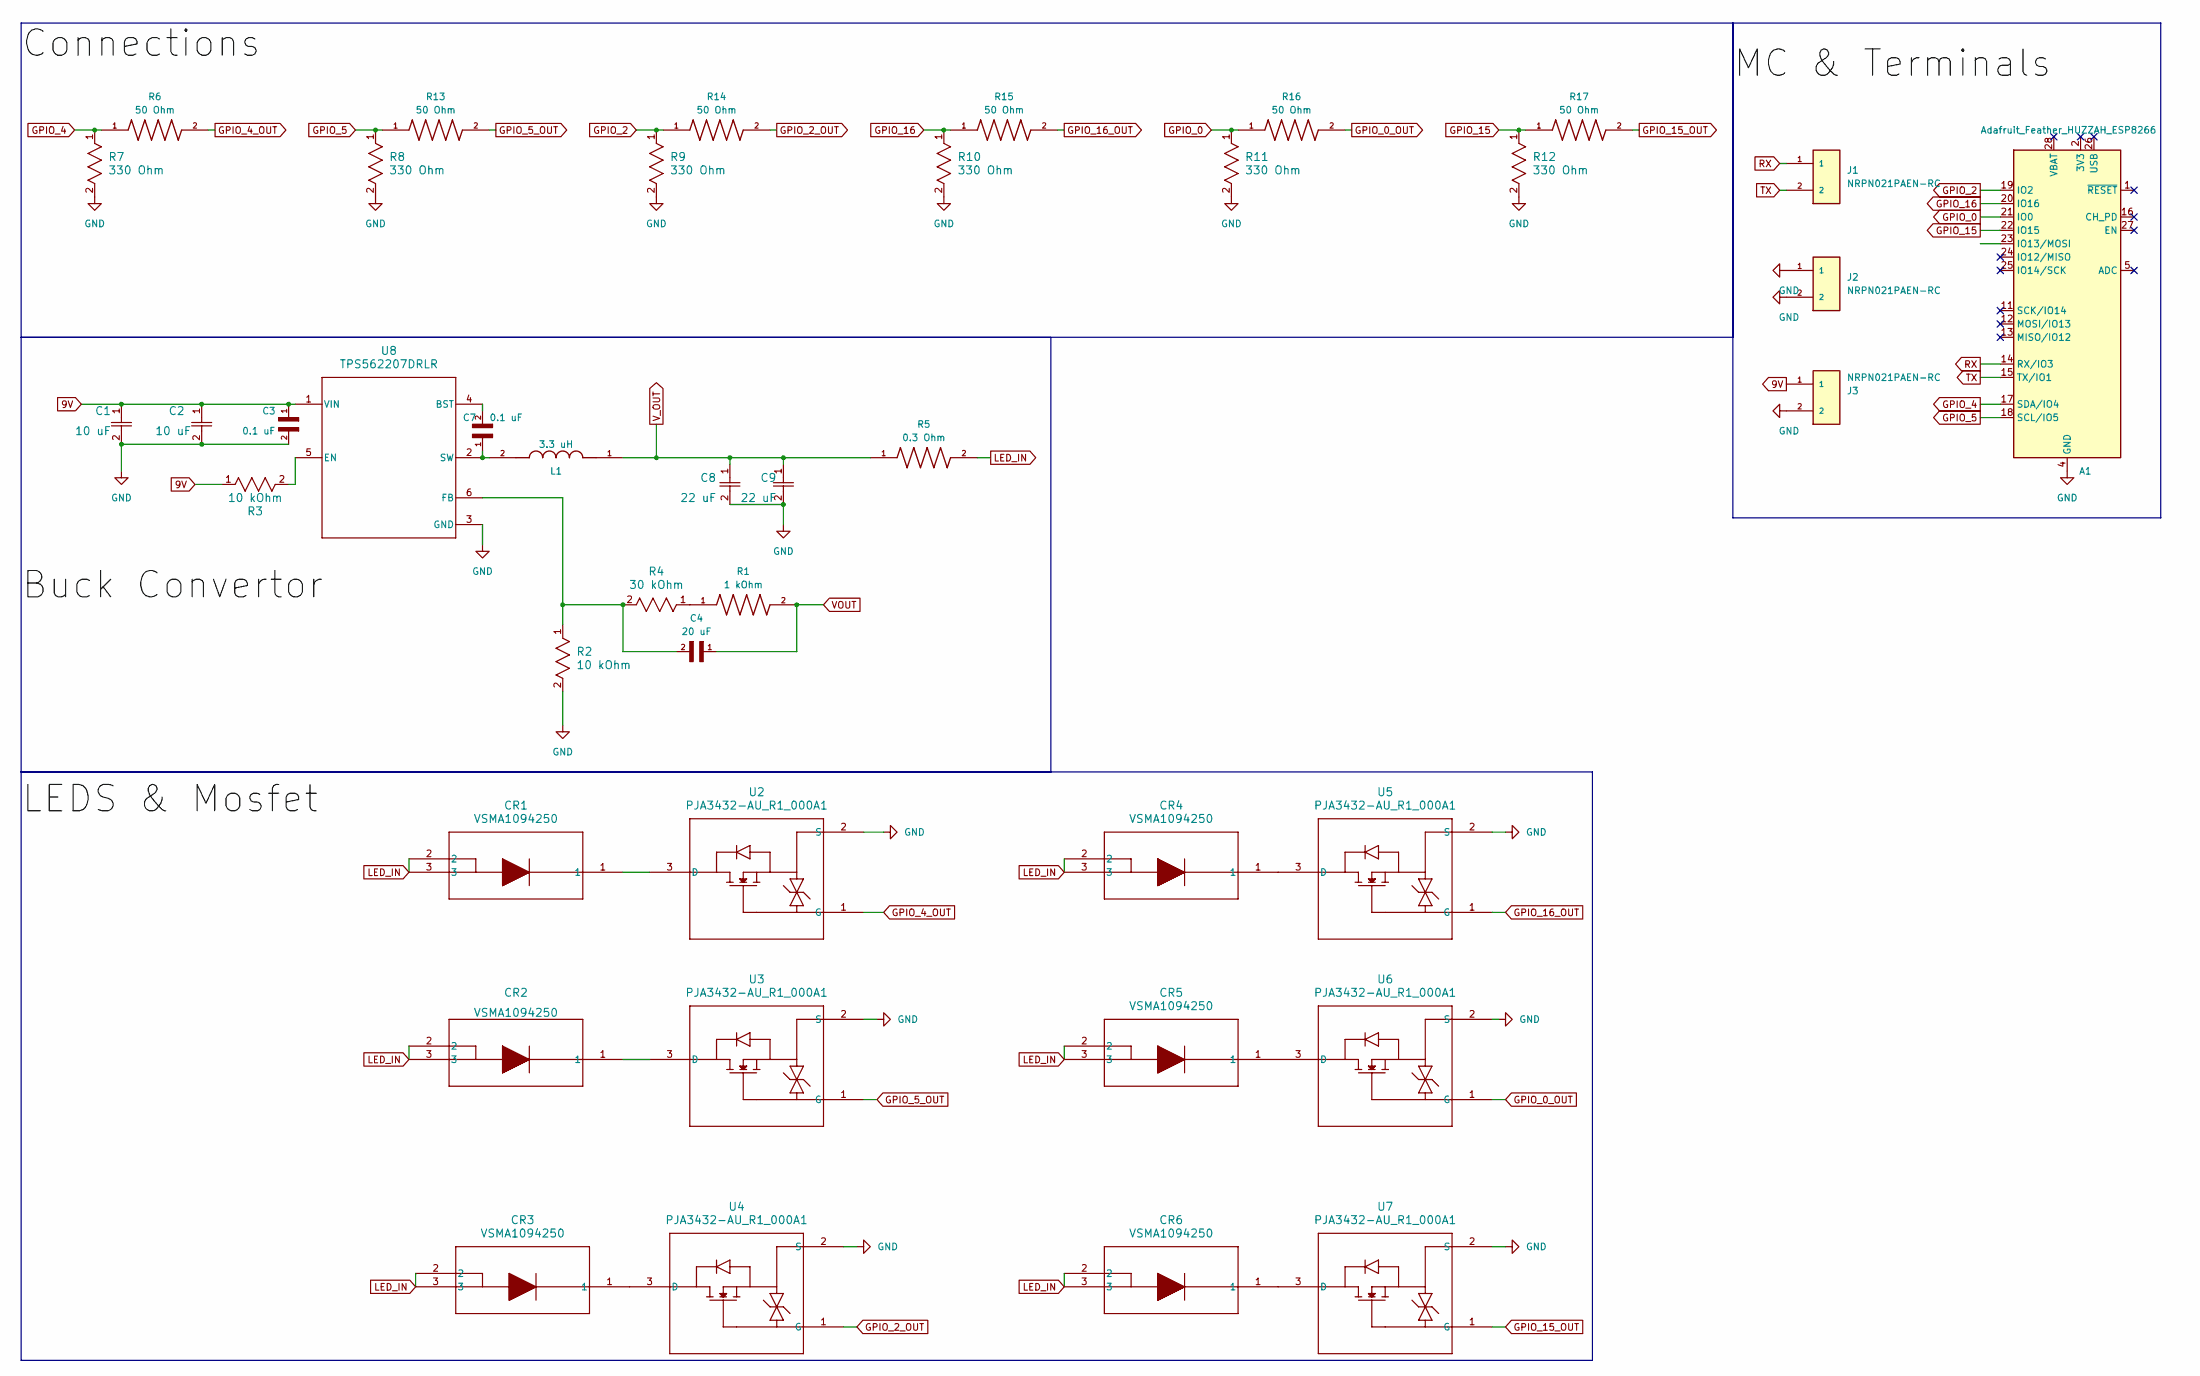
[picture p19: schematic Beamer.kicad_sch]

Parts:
A1: Adafruit_Feather_HUZZAH_ESP8266; Adafruit_Feather
C1, C2: 10 uF; C_0805_2012Metric_Pad1.18x1.45mm_HandSolder
C3, C7: 0.1 uF; C_0402_1005Metric_Pad0.74x0.62mm_HandSolder
C4: 20 uF; CAPC1810X80N
C8, C9: 22 uF; C_0603_1608Metric_Pad1.08x0.95mm_HandSolder
CR1, CR2, CR3, CR4, CR5, CR6: VSMA1094250; DIODE_VSMA1094250_VIS
J1, J2, J3: NRPN021PAEN-RC; PinHeader_1x02_P2.00mm_Vertical; PARTREV E
L1: 3.3 uH; IND_ASPI-4020S-3R3M-T; PARTREV 03.07.13
R1: 1 kOhm; R_0603_1608Metric_Pad0.98x0.95mm_HandSolder
R2, R3: 10 kOhm; R_0402_1005Metric_Pad0.72x0.64mm_HandSolder
R4: 30 kOhm; R_0402_1005Metric_Pad0.72x0.64mm_HandSolder
R5: 0.3 Ohm; R_0805_2012Metric_Pad1.20x1.40mm_HandSolder; PARTREV 3/1/2020
R6, R13, R14, R15, R16, R17: 50 Ohm; R_0603_1608Metric_Pad0.98x0.95mm_HandSolder
R7, R8, R9, R10, R11, R12: 330 Ohm; R_0603_1608Metric_Pad0.98x0.95mm_HandSolder
U2, U3, U4, U5, U6, U7: PJA3432-AU_R1_000A1; SOT-23-3
U8: TPS562207DRLR; SOT-666

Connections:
9V: C1.1, C2.1, C3.1, J3.1, R3.1, U8.1 (VIN)
GND: A1.4 (GND), C1.2, C2.2, C3.2, C8.2, C9.2, J2.1, J2.2, J3.2, R2.2, R7.2, R8.2, R9.2, R10.2, R11.2, R12.2, U2.2 (S), U3.2 (S), U4.2 (S), U5.2 (S), U6.2 (S), U7.2 (S), U8.3 (GND)
GPIO_0: A1.21 (IO0), R11.1, R16.1
GPIO_0_OUT: R16.2, U6.1 (G)
GPIO_2: A1.19 (IO2), R9.1, R14.1
GPIO_2_OUT: R14.2, U4.1 (G)
GPIO_4: A1.17 (SDA/IO4), R6.1, R7.1
GPIO_4_OUT: R6.2, U2.1 (G)
GPIO_5: A1.18 (SCL/IO5), R8.1, R13.1
GPIO_5_OUT: R13.2, U3.1 (G)
GPIO_15: A1.22 (IO15), R12.1, R17.1
GPIO_15_OUT: R17.2, U7.1 (G)
GPIO_16: A1.20 (IO16), R10.1, R15.1
GPIO_16_OUT: R15.2, U5.1 (G)
LED_IN: CR1.2, CR1.3, CR2.2, CR2.3, CR3.2, CR3.3, CR4.2, CR4.3, CR5.2, CR5.3, CR6.2, CR6.3, R5.2
unnamed: R1.1, R4.1
unnamed: CR1.1, U2.3 (D)
unnamed: CR2.1, U3.3 (D)
unnamed: CR3.1, U4.3 (D)
unnamed: CR4.1, U5.3 (D)
unnamed: CR5.1, U6.3 (D)
unnamed: CR6.1, U7.3 (D)
unnamed: C7.2, U8.4 (BST)
unnamed: R3.2, U8.5 (EN)
unnamed: C4.2, R2.1, R4.2, U8.6 (FB)
unnamed: C7.1, L1.2, U8.2 (SW)
RX: A1.14 (RX/IO3), J1.1
TX: A1.15 (TX/IO1), J1.2

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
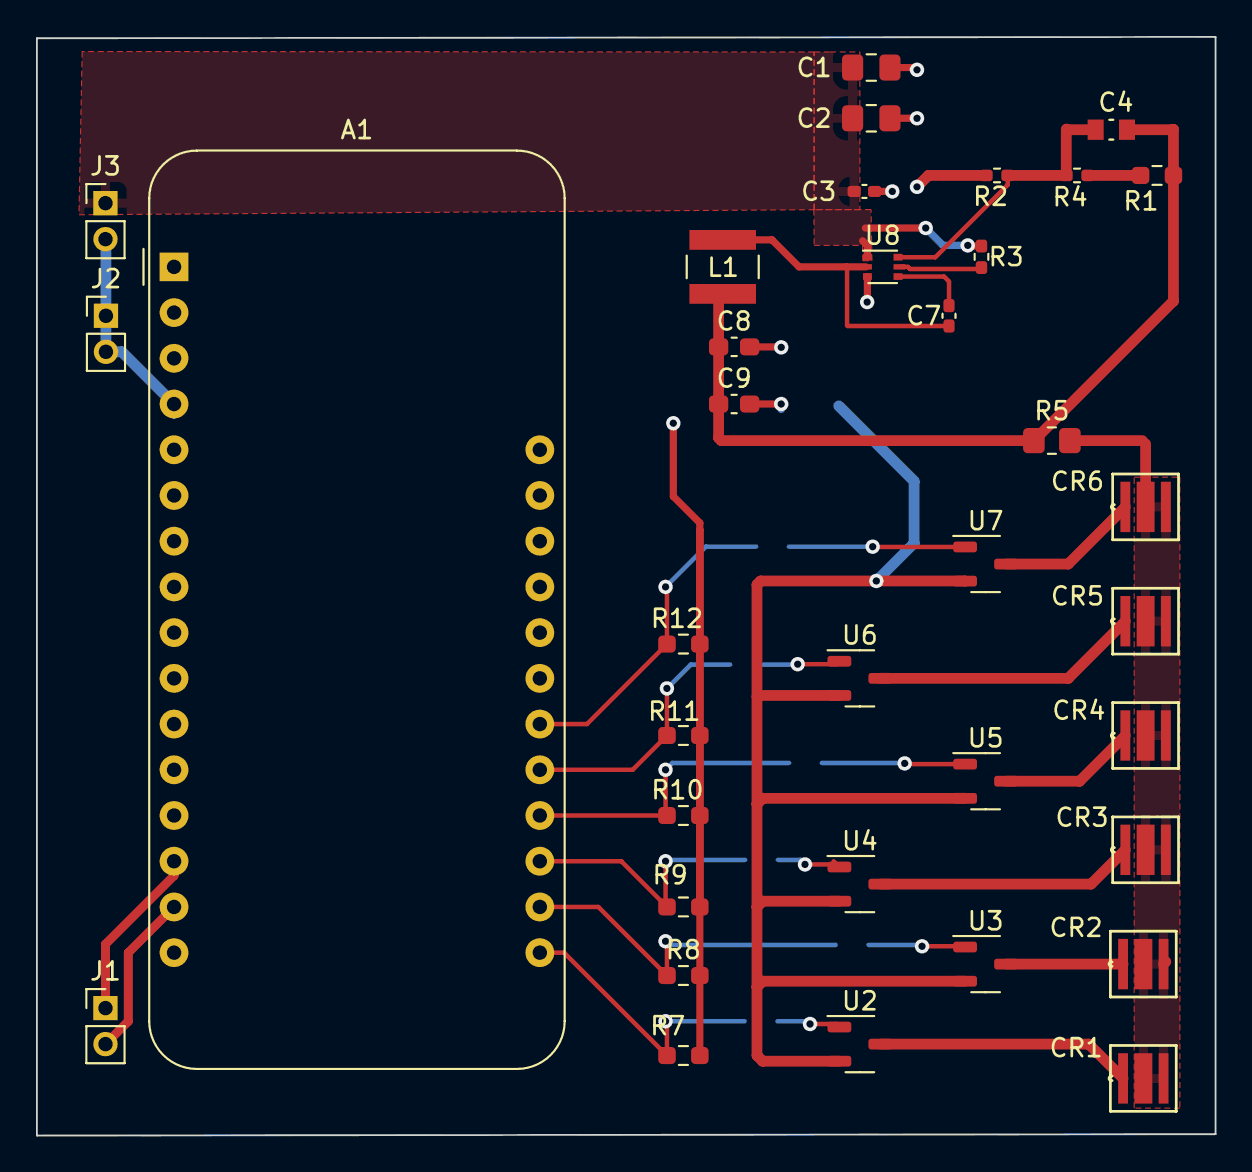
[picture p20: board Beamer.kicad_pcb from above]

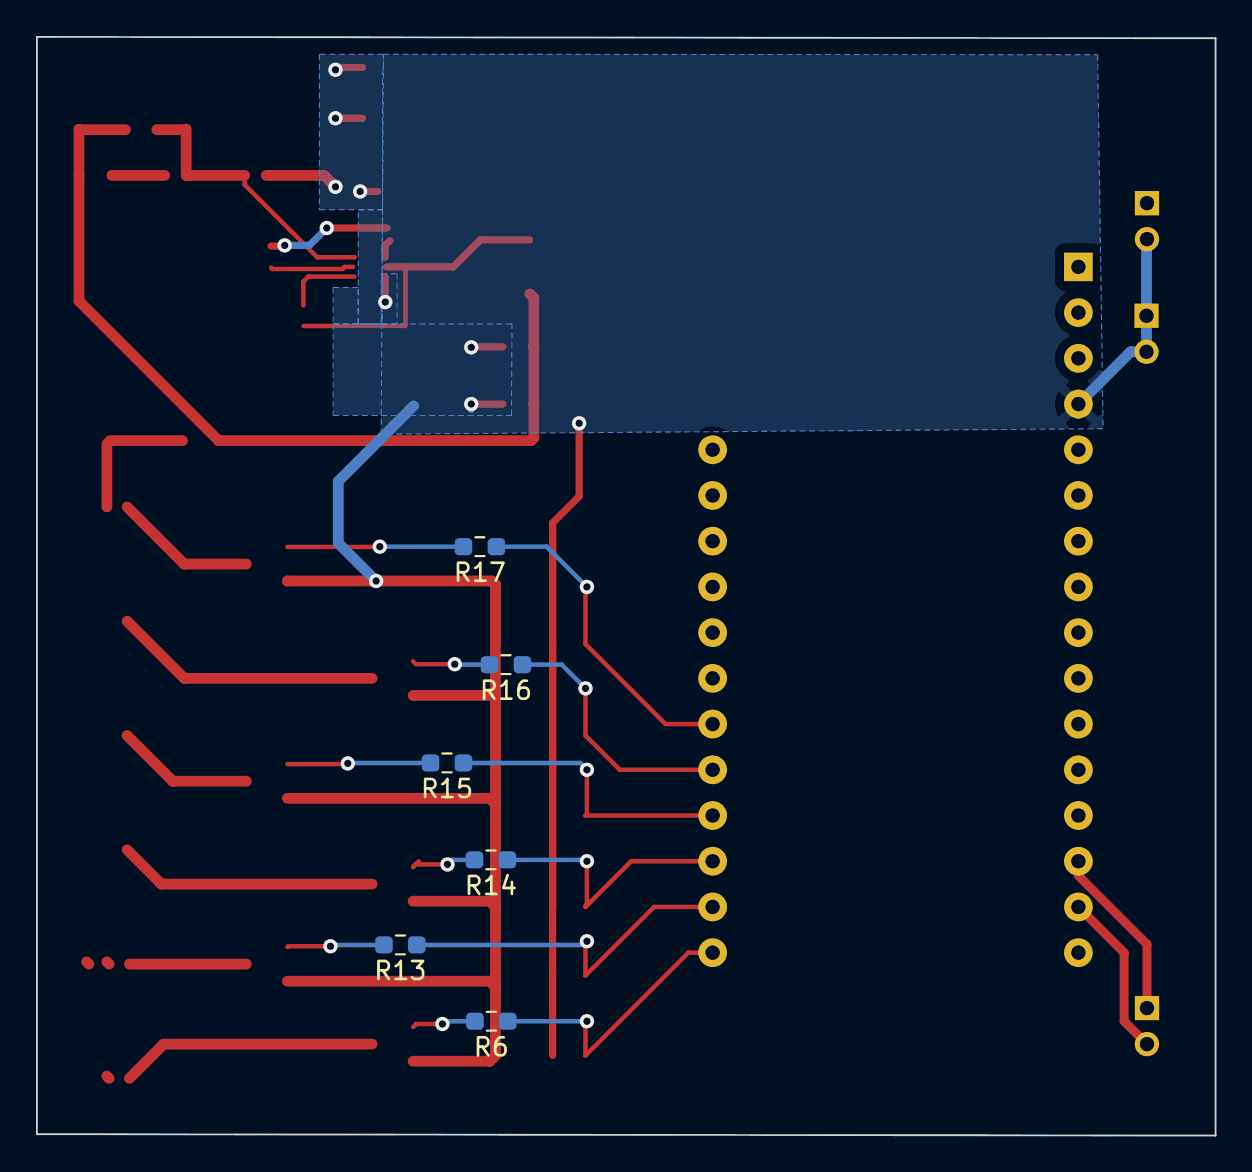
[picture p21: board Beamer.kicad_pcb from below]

Board: 2 copper layers, 65.5 x 61.0 mm, 42 parts (6 on the bottom side), 29 nets.

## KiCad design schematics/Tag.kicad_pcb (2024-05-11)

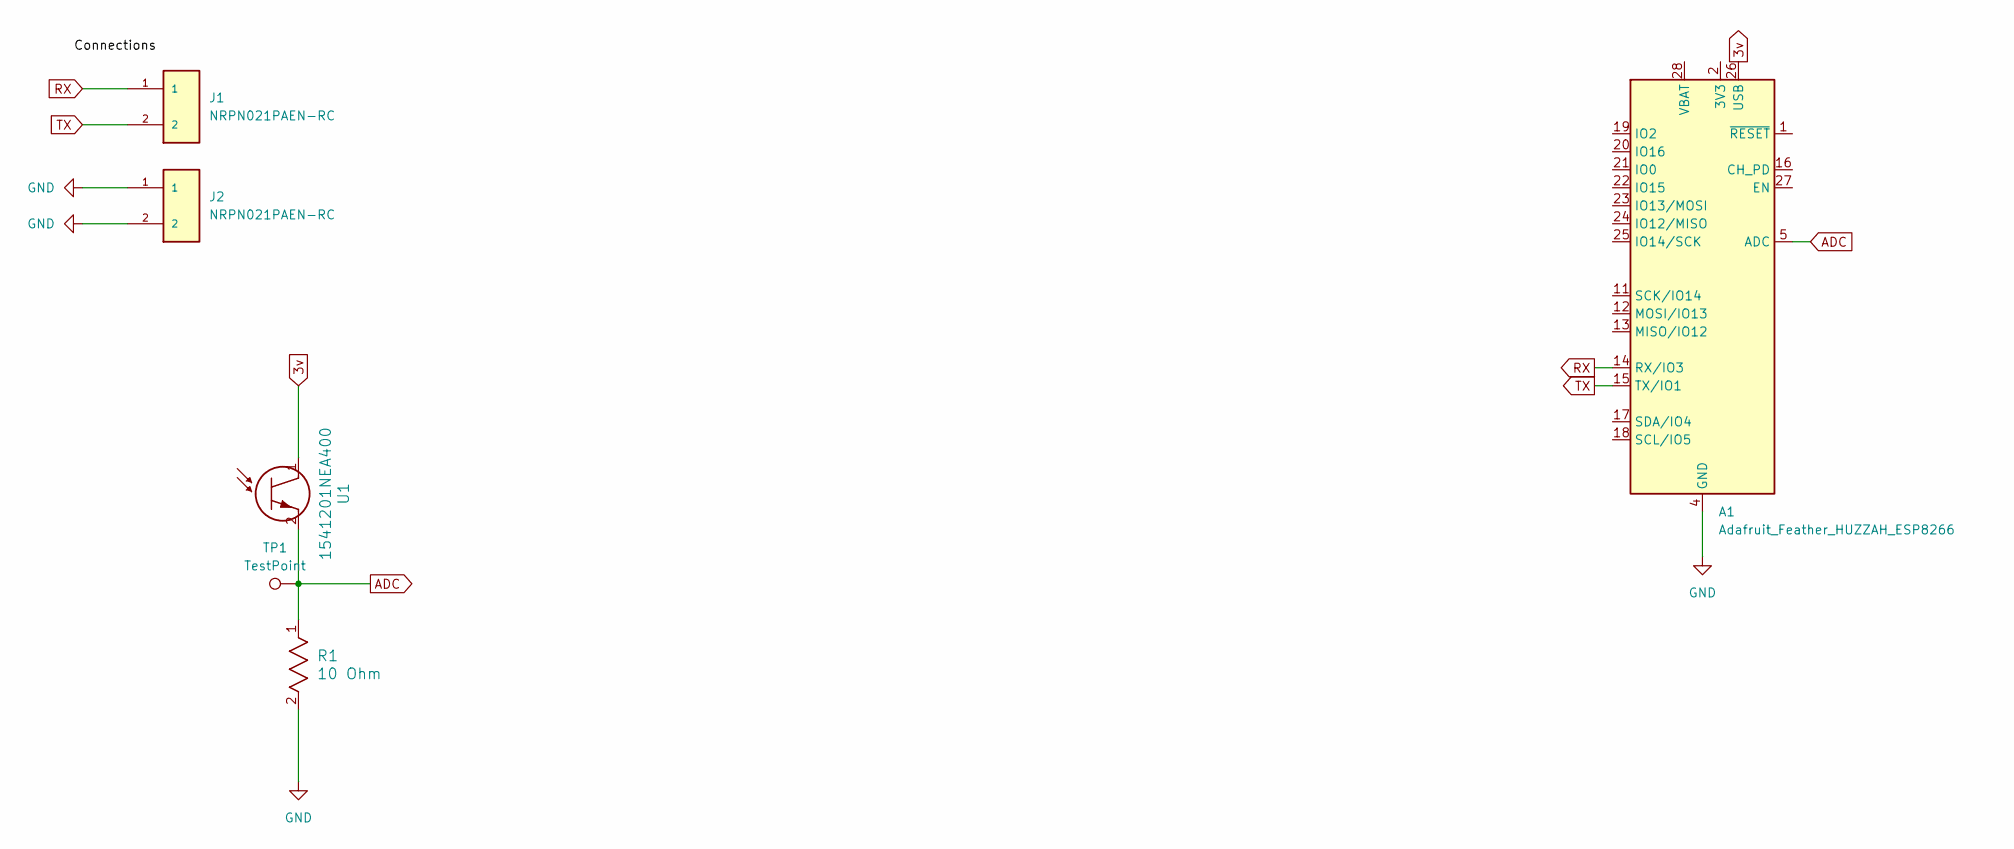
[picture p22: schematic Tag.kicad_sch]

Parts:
A1: Adafruit_Feather_HUZZAH_ESP8266; Adafruit_Feather
J1, J2: NRPN021PAEN-RC; PinHeader_1x02_P2.00mm_Vertical; PARTREV E
R1: 10 Ohm; R_0603_1608Metric_Pad0.98x0.95mm_HandSolder
TP1: TestPoint; TestPoint_Loop_D1.80mm_Drill1.0mm_Beaded
U1: 1541201NEA400; R_1206_3216Metric_Pad1.30x1.75mm_HandSolder

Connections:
3v: A1.26 (USB), U1.1
ADC: A1.5 (ADC), R1.1, TP1.1, U1.2
GND: A1.4 (GND), J2.1, J2.2, R1.2
RX: A1.14 (RX/IO3), J1.1
TX: A1.15 (TX/IO1), J1.2

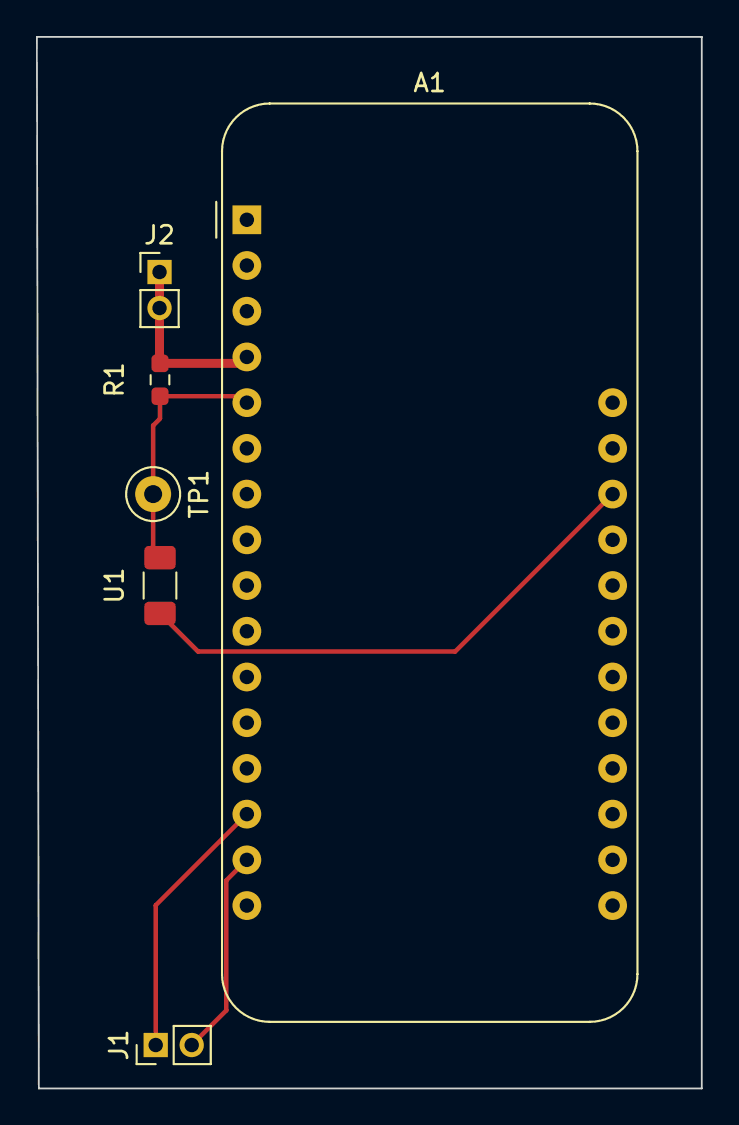
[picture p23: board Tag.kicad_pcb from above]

Board: 2 copper layers, 36.9 x 58.4 mm, 6 parts (0 on the bottom side), 5 nets.

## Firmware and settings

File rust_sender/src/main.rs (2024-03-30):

#![cfg_attr(not(debug_assertions), windows_subsystem = "windows")] // hide console window on Windows in release

use std::net::{UdpSocket, SocketAddr};
use std::thread;
use std::time::Duration;
use concurrent_queue::ConcurrentQueue;
use std::sync::Arc;


fn send_messages(sending_udp_port: u16) {
    let tag_hosts = vec!["192.168.0.12", "192.168.0.13"];
    let beamer_hosts = vec!["192.168.0.11", "192.168.0.14", "192.168.0.15", "192.168.0.16"];
    let NUM_BEAMERS = 4;

    thread::sleep(Duration::from_millis(1000));
    let mut counter = 0;
    let NUM_LEDS = 4;
    println!("starting send thread");

    let mut beamer_id = 0;
    let mut udp_hosts = tag_hosts.clone();
    while true {
        udp_hosts.push(beamer_hosts[beamer_id]);
        beamer_id = (beamer_id + 1) % beamer_hosts.len();
        // println!("UDP hosts: {:?}", udp_hosts);
        for udp_host in &udp_hosts {
            if *udp_host == "empty" {
                continue
            }
            let socket = UdpSocket::bind(format!("0.0.0.0:{}", sending_udp_port)).expect("Failed to bind socket");
            socket.set_nonblocking(true).expect("Failed to set non-blocking");
            let msg = counter.to_string();
            socket.send_to(msg.as_bytes(), format!("{}:{}", udp_host, sending_udp_port))
                .expect("Failed to send message");
        }
        udp_hosts.pop();
        counter = (counter+1) % NUM_BEAMERS;
        thread::sleep(Duration::from_millis(120));
    }
}

fn message_handler(q: &ConcurrentQueue<(String, SocketAddr)>) {
    loop {
        if !q.is_empty() {
            let pair = q.pop().unwrap();
            let values: Vec<i32> = pair.0.split_whitespace().map(|s| s.parse().unwrap()).collect();
            // print values to console with each digit being padded to 3 spaces

            let padded_values: Vec<String> = values.iter().map(|&num| format!("{:03}", num)).collect();
            println!("{} : {:?} ", pair.1, padded_values);
        }
    }
}

fn receive_messages(listening_udp_port: u16, q: &ConcurrentQueue<(String, SocketAddr)>) {
    // println!("starting recv thread");
    let socket = UdpSocket::bind(format!("0.0.0.0:{}", listening_udp_port)).expect("Failed to bind socket");
    socket.set_nonblocking(true).expect("Failed to set non-blocking");
    let mut buffer = [0; 1024];
    loop {
        match socket.recv_from(&mut buffer) {
            Ok((size, addr)) => {
                let data = String::from_utf8_lossy(&buffer[..size]);
                let _ = q.push((data.to_string(), addr));
                // println!("Received Messages: {} from {}", data, addr);
            }
            Err(_) => {
            }
        }
    }
}

fn main() {
    // let udp_hosts = vec!["192.168.0.11"];
    let sending_udp_port = 4210;
    let listening_udp_port = 5000;

    println!("Hello send thread");

    let message_queue: Arc<ConcurrentQueue<(String, SocketAddr)>> = Arc::new(ConcurrentQueue::unbounded());

    let queue_clone = Arc::clone(&message_queue);
    // let receive_thread = thread::spawn(move || receive_messages(listening_udp_port, &queue_clone));

    let queue_clone = Arc::clone(&message_queue);
    // let handle_received_value = thread::spawn(move || message_handler(&queue_clone));

    let send_thread = thread::spawn(move || send_messages(sending_udp_port));

    send_thread.join().expect("Send thread panicked");
    // receive_thread.join().expect("Receive thread panicked");
    // handle_received_value.join().expect("message handler thread panicked");
}

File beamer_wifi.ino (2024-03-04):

#include <ESP8266WiFi.h>
#include <WiFiUdp.h>

const int NUM_LEDS = 4;
int LED_GPIOS[NUM_LEDS] = {4, 5, 2, 16};

/* Setup WiFi paramteres */
const char* ssid     = "dlink-A40C";
const char* password = "qybmo02053";
IPAddress local_ip(192, 168, 0, 16);
IPAddress gateway(192, 168, 0, 1);
IPAddress subnet(255, 255, 255, 0);

WiFiUDP Udp;
const char* host = "192.168.75.154";
unsigned int portToListen = 4210;  // local port to listen on
// unsigned int portToSend = 5000;
char incomingPacket[255];  // buffer for incoming packets
char replyPacket[20];
unsigned long timeWindow = 10;
// unsigned long cycleWindow = 10;

unsigned long readingWindow = 6;
unsigned long timeDelay = (timeWindow - readingWindow) / 2;
unsigned long startTime;
unsigned long currentTime;

bool startReading = false;
bool startDelay = false;

void setup() {
  Serial.begin(19200);
  // pinMode(0, OUTPUT);
  Serial.printf("Time window: %u, Reading window: %u\n", timeWindow, readingWindow);

  // turn LED ON by default
  // digitalWrite(0, LOW);

  // We start by connecting to a WiFi network

  Serial.print("Connecting to ");
  Serial.println(ssid);
  
  
  WiFi.config(local_ip, gateway, subnet);
  WiFi.begin(ssid, password);
  
  while (WiFi.status() != WL_CONNECTED) {
    delay(100);
    Serial.print(".");
  }

  Serial.println("");
  Serial.println("WiFi connected");  
  // turn LED OFF when WiFi is connected
  // digitalWrite(0, HIGH);
  Serial.println("IP address: ");
  Serial.println(WiFi.localIP());
  uint16 ab = Udp.begin(portToListen);
  // Serial.printf("Now listening at IP %s, UDP port %d, %d\n", WiFi.localIP().toString().c_str(), portToListen, ab);

  int i;
  int ALL_LED_GPIOS[6] = {4, 5, 2, 16, 0, 15};
  for (i=0;i<6;i++){
    pinMode(ALL_LED_GPIOS[i], OUTPUT); // Set the pin as an OUTPUT
    digitalWrite(ALL_LED_GPIOS[i], LOW);
  }
}

int ledId = 0;
// int cycleCounter = 0;
int counter;
bool firstDelay;

void loop() {
  currentTime = millis();
  int packetSize = Udp.parsePacket();

  if (packetSize) {
    Serial.printf("R %d,%u\n", ledId, currentTime);
    // received a UDP packet, start light cycle
    
    startTime = currentTime;

    startDelay = true;

    if(ledId != 0) {
      timeDelay /= 2;
      digitalWrite(LED_GPIOS[ledId], LOW);
    }

    // cycleCounter = 1; // so we go into else if block once cycle time has been reached
    ledId = 0;
    // digitalWrite(LED_GPIOS[ledId], HIGH);
    // Serial.println("Delay started");

  }


  if(startDelay && (currentTime - startTime >= timeDelay)) {
      // Serial.println("Delay finished");
      // Serial.printf("Turning on LED %d\n", ledId);
      if(ledId < NUM_LEDS) {
        digitalWrite(LED_GPIOS[ledId], HIGH);
      } else {
        Serial.println("LEDID TOO LARGE");
        Serial.println(ledId);
      }
      startDelay = false;
      startTime = currentTime;
      startReading = true;
  }

  if(startReading) {
    if (currentTime - startTime >= readingWindow) {
      digitalWrite(LED_GPIOS[ledId], LOW);
      // Serial.printf("Turning OFF LED %d\n", ledId);
      startReading = false;
      if(ledId == 0) {
        timeDelay *= 2;
      }
      if(ledId >= NUM_LEDS - 1) {
        timeDelay /= 2;
        startDelay = false;
        ledId = 0;
      } else {
        ledId += 1;
        startDelay = true;
        // Serial.printf("2 Delays started %u\n", timeDelay);
      }
      startTime = currentTime; 
    }
  }
}

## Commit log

2023-07-05 add arduino tag code
2023-07-18 UART_Testing for Tag (Manual Analog using voltage divider working)
2023-07-22 Tag: Loop3 + Beamer: Basic Setup without enable pin done
2023-07-27 receiving inputs from arduino
2023-07-28 BEAMER INTERRUPT WAITING
2024-01-25 fix arduino_1
2024-01-25 use built-in LED for WiFi status
2024-01-25 update LED status indicator
2024-01-25 start listening and transmission sockets on separate threads
2024-02-08 add worker thread for handling received results and modify arduino response packet to round-trip received msg
2024-02-08 turn leds off on arduino once 100 msgs received to test one-way time
2024-02-10 revert to working send/recieve
    [main.rs]
2024-02-20 reduce print stmts
2024-02-20 remove old arduino files
2024-02-21 use a single sync for each cycle of 6 leds for the beamer
2024-02-29 beamer: account for early sync, WiFi: vector prints
2024-03-03 1D Visualization with 4 edge case handled
2024-03-03 Beamer uses 4 LEDs,
2024-03-04 added test, fixed regions, aaaahhhhhhh
    [main.rs]
2024-03-04 Switch to 5 beamrs
2024-05-11 Restructure Repository
    [Beamer.kicad_pcb, Beamer.kicad_sch, Beamer_box_complete.3mf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]
